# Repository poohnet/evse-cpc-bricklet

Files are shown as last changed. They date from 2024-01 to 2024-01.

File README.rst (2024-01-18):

EVSE CPC Bricklet
=================

**This Bricklet is currently in development.**

This repository contains the firmware source code and the hardware design
files. The documentation generator configs can be found at
https://github.com/Tinkerforge/generators

Repository Content
------------------

software/:
 * examples/: Examples for all supported languages
 * build/: Compiled files
 * src/: Source code of firmware
 * Makefile: Makefile to build project

hardware/:
 * Contains KiCad project files and additionally schematics as PDF

datasheets/:
 * Contains datasheets for sensors and complex ICs that are used

Hardware
--------

The hardware is designed with the open source EDA Suite KiCad
(http://www.kicad.org). Before you are able to open the files,
you have to install the Tinkerforge kicad-libraries
(https://github.com/Tinkerforge/kicad-libraries). You can either clone
them directly in hardware/ or clone them in a separate folder and
symlink them into hardware/
(ln -s kicad_path/kicad-libraries project_path/hardware). After that you
can open the .pro file in hardware/ with KiCad and from there view and
modify the schematics and the PCB layout.

Software
--------

If you want to do your own Brick/Bricklet firmware development we highly
recommend that you use our build environment setup script and read the
tutorial (https://www.tinkerforge.com/en/doc/Tutorials/Tutorial_Build_Environment/Tutorial.html).

To compile the C code we recommend you to install the newest GNU Arm Embedded
Toolchain (https://launchpad.net/gcc-arm-embedded/+download).
You also need to install bricklib2 (https://github.com/Tinkerforge/bricklib2).

You can either clone it directly in software/src/ or clone it in a
separate folder and symlink it into software/src/
(ln -s bricklib_path/bricklib2 project_path/software/src/). Finally make sure to
have CMake installed (http://www.cmake.org/cmake/resources/software.html).

After that you can build the firmware by invoking make in software/.
The firmware (.zbin) can then be found in software/build/ and uploaded
with brickv (click button "Flashing" on start screen).

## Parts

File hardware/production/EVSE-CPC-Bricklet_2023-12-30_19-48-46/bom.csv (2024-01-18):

Designator | Footprint | Quantity | Value | LCSC Part #
C1 | C0805 | 1 | 10uF | C1222438
C2 | C0603 | 1 | 1uF | C513775
C3 | C0402 | 1 | 220pF | C107025
C4 | C0603 | 1 | 100nF | C30926
CN1 | CONN-SMD_7P-P1.25_HCTL_HC-GH-7PWTKK | 1 | HC-GH-7PWTKK | C3011949
CN2 | CONN-TH_4P-P3.81_DB2ERC-3.81-4P | 1 | DB2ERC-3.81-4P | C395698
H1 | HDR-TH_3P-P1.27-V-M | 1 | X1311WV-03J-C18D27 | C2881648
LED1, LED2, LED3 | LED0603-RD | 3 | blue | C84266
R1, R2, R3, R4, R5 | R0603 | 5 | 1K | C22548
RN1 | RES-ARRAY-SMD_0603-8P-L3.2-W1.6-BL | 1 | CRA034RJ82RP05 | C429276
U1 | VQFN-24_L4.0-W4.0-P0.50-TL-EP2.7 | 1 | XMC1302-Q024X0032-AB | C5121285
U2, U3 | SOP-4_L4.3-W4.4-P2.54-LS7.0-BL | 2 | AQY282SX | C250827
VAL | WEEE_7mm | 1 | WEEE_7mm

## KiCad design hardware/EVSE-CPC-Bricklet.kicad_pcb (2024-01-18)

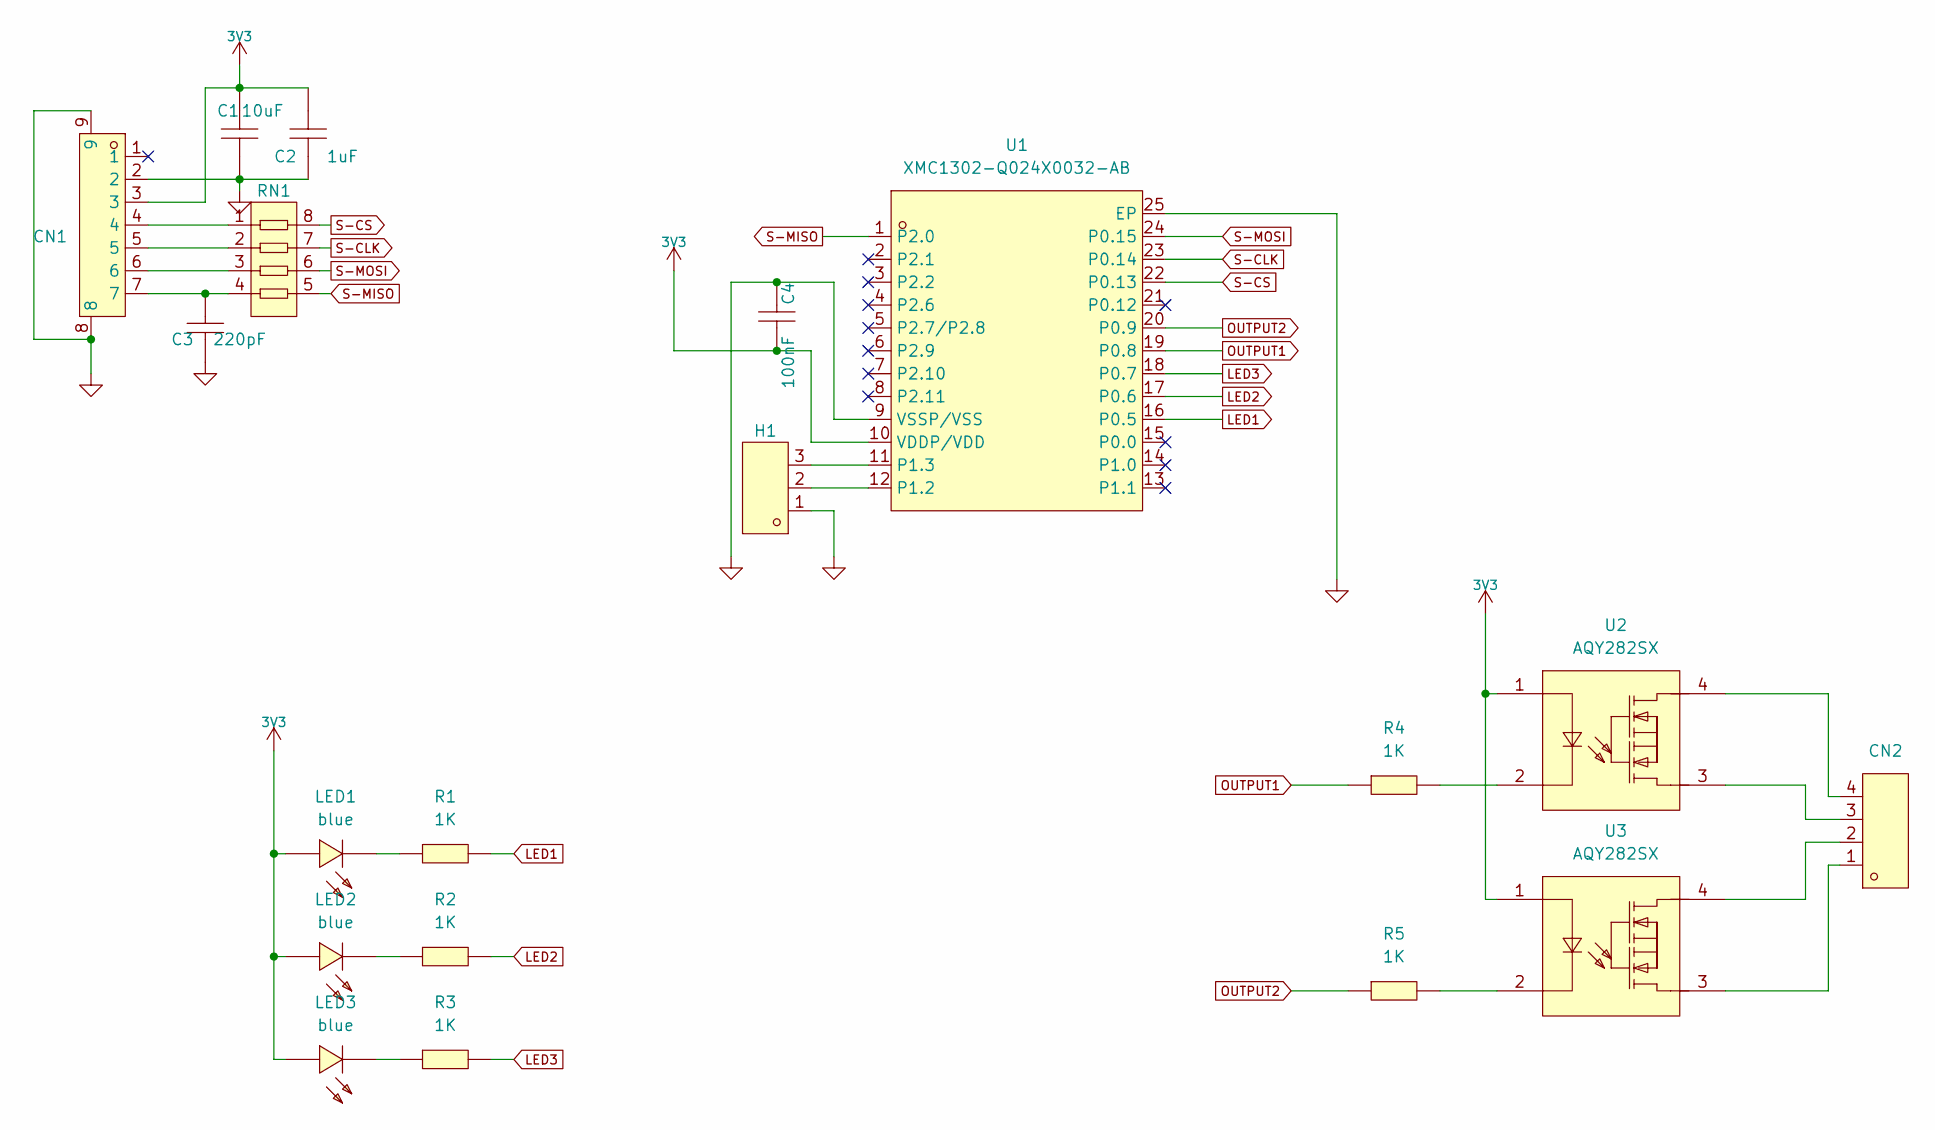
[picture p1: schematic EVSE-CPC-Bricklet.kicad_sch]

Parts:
C1: 10uF; C0805; LCSC Part C1222438
C2: 1uF; C0603; LCSC Part C513775
C3: 220pF; C0402; LCSC Part C107025
C4: 100nF; C0603; LCSC Part C30926
CN1: HC-GH-7PWTKK; CONN-SMD_7P-P1.25_HCTL_HC-GH-7PWTKK; LCSC Part C3011949
CN2: DB2ERC-3.81-4P; CONN-TH_4P-P3.81_DB2ERC-3.81-4P; LCSC Part C395698
H1: X1311WV-03J-C18D27; HDR-TH_3P-P1.27-V-M; LCSC Part C2881648
LED1, LED2, LED3: blue; LED0603-RD; LCSC Part C84266
R1, R2, R3, R4, R5: 1K; R0603; LCSC Part C22548
RN1: CRA034RJ82RP05; RES-ARRAY-SMD_0603-8P-L3.2-W1.6-BL; LCSC Part C429276
U1: XMC1302-Q024X0032-AB; VQFN-24_L4.0-W4.0-P0.50-TL-EP2.7; LCSC Part C5121285
U2, U3: AQY282SX; SOP-4_L4.3-W4.4-P2.54-LS7.0-BL; LCSC Part C250827

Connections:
3V3: C1.1, C2.1, C4.2, CN1.3, LED1.2 (+), LED2.2 (+), LED3.2 (+), U1.10 (VDDP/VDD), U2.1, U3.1
GND: C1.2, C2.2, C3.2, C4.1, CN1.2, CN1.8, CN1.9, H1.1, U1.9 (VSSP/VSS), U1.25 (EP)
LED1: R1.2, U1.16 (P0.5)
LED2: R2.2, U1.17 (P0.6)
LED3: R3.2, U1.18 (P0.7)
unnamed: C3.1, CN1.7, RN1.4
unnamed: CN1.4, RN1.1
unnamed: CN1.5, RN1.2
unnamed: CN1.6, RN1.3
unnamed: CN2.1, U3.3
unnamed: CN2.2, U3.4
unnamed: CN2.3, U2.3
unnamed: CN2.4, U2.4
unnamed: LED1.1 (-), R1.1
unnamed: LED2.1 (-), R2.1
unnamed: LED3.1 (-), R3.1
unnamed: R4.2, U2.2
unnamed: R5.2, U3.2
unnamed: H1.2, U1.12 (P1.2)
unnamed: H1.3, U1.11 (P1.3)
OUTPUT1: R4.1, U1.19 (P0.8)
OUTPUT2: R5.1, U1.20 (P0.9)
S-CLK: RN1.7, U1.23 (P0.14)
S-CS: RN1.8, U1.22 (P0.13)
S-MISO: RN1.5, U1.1 (P2.0)
S-MOSI: RN1.6, U1.24 (P0.15)

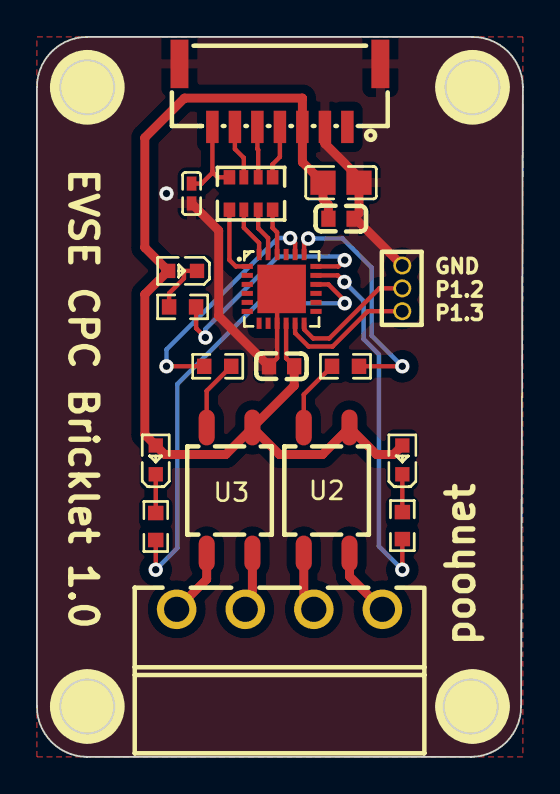
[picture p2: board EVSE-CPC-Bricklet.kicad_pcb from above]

Board: 2 copper layers, 27.0 x 40.0 mm, 20 parts (1 on the bottom side), 26 nets.

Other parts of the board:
VAL: WEEE_7mm

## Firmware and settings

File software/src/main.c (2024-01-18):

/* evse-cpc-bricklet
 * Copyright (C) 2024 Thomas Hein <github@poohnet.de>
 *
 * main.c: Initialization for EVSE CPC Bricklet
 *
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
 * You should have received a copy of the GNU Lesser General Public
 * License along with this library; if not, write to the
 * Free Software Foundation, Inc., 59 Temple Place - Suite 330,
 * Boston, MA 02111-1307, USA.
 */

#include <stdio.h>
#include <stdbool.h>

#include "configs/config.h"

#include "bricklib2/bootloader/bootloader.h"
#include "bricklib2/hal/system_timer/system_timer.h"
#include "bricklib2/logging/logging.h"
#include "communication.h"

int main(void) {
	logging_init();
	logd("Start EVSE CPC Bricklet\n\r");

	communication_init();

	while(true) {
		bootloader_tick();
		communication_tick();
	}
}

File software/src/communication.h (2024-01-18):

/* evse-cpc-bricklet
 * Copyright (C) 2024 Thomas Hein <github@poohnet.de>
 *
 * communication.h: TFP protocol message handling
 *
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
 * You should have received a copy of the GNU Lesser General Public
 * License along with this library; if not, write to the
 * Free Software Foundation, Inc., 59 Temple Place - Suite 330,
 * Boston, MA 02111-1307, USA.
 */

#ifndef COMMUNICATION_H
#define COMMUNICATION_H

#include <stdint.h>
#include <stdbool.h>

#include "bricklib2/protocols/tfp/tfp.h"
#include "bricklib2/bootloader/bootloader.h"

// Default functions
BootloaderHandleMessageResponse handle_message(const void *data, void *response);
void communication_tick(void);
void communication_init(void);

// Constants

#define EVSE_CPC_CHANNEL_LED_CONFIG_OFF 0
#define EVSE_CPC_CHANNEL_LED_CONFIG_ON 1
#define EVSE_CPC_CHANNEL_LED_CONFIG_SHOW_HEARTBEAT 2
#define EVSE_CPC_CHANNEL_LED_CONFIG_SHOW_CHANNEL_STATUS 3

#define EVSE_CPC_BOOTLOADER_MODE_BOOTLOADER 0
#define EVSE_CPC_BOOTLOADER_MODE_FIRMWARE 1
#define EVSE_CPC_BOOTLOADER_MODE_BOOTLOADER_WAIT_FOR_REBOOT 2
#define EVSE_CPC_BOOTLOADER_MODE_FIRMWARE_WAIT_FOR_REBOOT 3
#define EVSE_CPC_BOOTLOADER_MODE_FIRMWARE_WAIT_FOR_ERASE_AND_REBOOT 4

#define EVSE_CPC_BOOTLOADER_STATUS_OK 0
#define EVSE_CPC_BOOTLOADER_STATUS_INVALID_MODE 1
#define EVSE_CPC_BOOTLOADER_STATUS_NO_CHANGE 2
#define EVSE_CPC_BOOTLOADER_STATUS_ENTRY_FUNCTION_NOT_PRESENT 3
#define EVSE_CPC_BOOTLOADER_STATUS_DEVICE_IDENTIFIER_INCORRECT 4
#define EVSE_CPC_BOOTLOADER_STATUS_CRC_MISMATCH 5

#define EVSE_CPC_STATUS_LED_CONFIG_OFF 0
#define EVSE_CPC_STATUS_LED_CONFIG_ON 1
#define EVSE_CPC_STATUS_LED_CONFIG_SHOW_HEARTBEAT 2
#define EVSE_CPC_STATUS_LED_CONFIG_SHOW_STATUS 3

// Function and callback IDs and structs
#define FID_SET_VALUE 1
#define FID_GET_VALUE 2
#define FID_SET_CHANNEL_LED_CONFIG 3
#define FID_GET_CHANNEL_LED_CONFIG 4


typedef struct {
	TFPMessageHeader header;
	bool channel0;
	bool channel1;
} __attribute__((__packed__)) SetValue;

typedef struct {
	TFPMessageHeader header;
} __attribute__((__packed__)) GetValue;

typedef struct {
	TFPMessageHeader header;
	bool channel0;
	bool channel1;
} __attribute__((__packed__)) GetValue_Response;

typedef struct {
	TFPMessageHeader header;
	uint8_t channel;
	uint8_t config;
} __attribute__((__packed__)) SetChannelLEDConfig;

typedef struct {
	TFPMessageHeader header;
	uint8_t channel;
} __attribute__((__packed__)) GetChannelLEDConfig;

typedef struct {
	TFPMessageHeader header;
	uint8_t config;
} __attribute__((__packed__)) GetChannelLEDConfig_Response;


// Function prototypes
BootloaderHandleMessageResponse set_value(const SetValue *data);
BootloaderHandleMessageResponse get_value(const GetValue *data, GetValue_Response *response);
BootloaderHandleMessageResponse set_channel_led_config(const SetChannelLEDConfig *data);
BootloaderHandleMessageResponse get_channel_led_config(const GetChannelLEDConfig *data, GetChannelLEDConfig_Response *response);

// Callbacks


#define COMMUNICATION_CALLBACK_TICK_WAIT_MS 1
#define COMMUNICATION_CALLBACK_HANDLER_NUM 0
#define COMMUNICATION_CALLBACK_LIST_INIT \


#endif

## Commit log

2024-01-18 Add initial files and directories
    [cmake_config_custom.txt]
2024-01-18 Add KiCad and JLCPCB production files
    [EVSE-CPC-Bricklet.kicad_pcb, EVSE-CPC-Bricklet.kicad_sch, bom.csv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]
2024-01-19 Relay configuration
2024-01-24 fix relay configuration
